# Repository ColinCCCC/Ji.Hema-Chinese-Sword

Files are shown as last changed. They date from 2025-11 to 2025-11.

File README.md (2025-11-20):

# 兵击中国剑『巽』



## 声明

本项目遵循[MIT协议](https://mitsloan.mit.edu/licensing)，允许自由使用、复制、修改、合并、发布、分发和商业化。

不保障项目绝对安全，使用本项目请自负一切后果。

本项目为减伤体育用品设计，请勿用于违反法律法规用途。

制作成品**无需用到任何工业设计专业知识**，如有兴趣，可跟随[下方教程](https://github.com/ColinCCCC/Ji.Hema-Chinese-Sword/tree/main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)进行制作。

## 成品数据

- 本项目由[风灵剑阁](https://space.bilibili.com/277525213?spm_id_from=333.337.0.0)进行指导，为用于兵击对练的中国剑钢剑设计，全长100cm，柄长22cm（计入剑首、剑格）。

- 剑身无渐薄，项目通过直接设计剑身形状，以符合真剑质量分布，并达成减伤要求。

- 倒角抛光前，剑条重量约530g。使用70%petg打印剑柄，并为所有孔位安装夹板螺母后，全重约700g。具体情况视材料与工艺而定。

- 经测试，若选用3mm65Mn或60Si2Mn板材，剑条刺弯压力约8.0kg。

## 使用教程

### 成品制作

#### 剑条切割

在淘宝等电商应用，搜索并查找提供**65Mn板材激光切割定制**服务的商家，按需选择合适的商品页面，并联系客服。

为商家提供所需的**DXF文件或DWG文件**，按需求说明**切割的数量与厚度**，待商家报价后，支付并提供收货地址，即可等待切割成品送达。

*所需DXF/DWG文件及其对应厚度如下：*

- 剑条【3mm】[blade.DXF](https://github.com/ColinCCCC/Ji.Hema-Chinese-Sword/blob/main/blade.DXF)
- 剑条【3mm】[blade.DWG](https://github.com/ColinCCCC/Ji.Hema-Chinese-Sword/blob/main/blade.DWG)

#### 手柄打印

若自备3D打印机，可以自行下载项目中的**STL文件**进行切片打印。

若无3D打印机，可在闲鱼搜索附近提供3D打印服务的商户，提供项目中的**STL文件**，打印后取货。

*所需STL文件及其对应厚度如下：*

- 剑柄（半边）[hdl.STL](https://github.com/ColinCCCC/Ji.Hema-Chinese-Sword/blob/main/hdl.STL)

#### 圆角与抛光

为保障对练安全性，**请务必对剑条进行圆角处理**。若希望追求美观性，可进一步对剑条表面进行抛光。

圆角与抛光需要用到砂带机或角磨机，可以选择自行打磨，或就近寻找五金店，请工作人员协助打磨。

#### 装配

剑柄采用4个M6*14，杆径8的夹板螺母固定，请自行购置。

### 设计修改

项目使用SOLIDWORKS2025进行设计，项目已附带所有原工程文件。

*所有SLDPRT文件如下：*

- 剑条 [blade.SLDPRT](https://github.com/ColinCCCC/Ji.Hema-Chinese-Sword/blob/main/blade.SLDPRT)

- 剑柄（半边）[hdl.SLDPRT](https://github.com/ColinCCCC/Ji.Hema-Chinese-Sword/blob/main/hdl.SLDPRT)

使用者可以在此基础上，按需求进行修改或再创作。

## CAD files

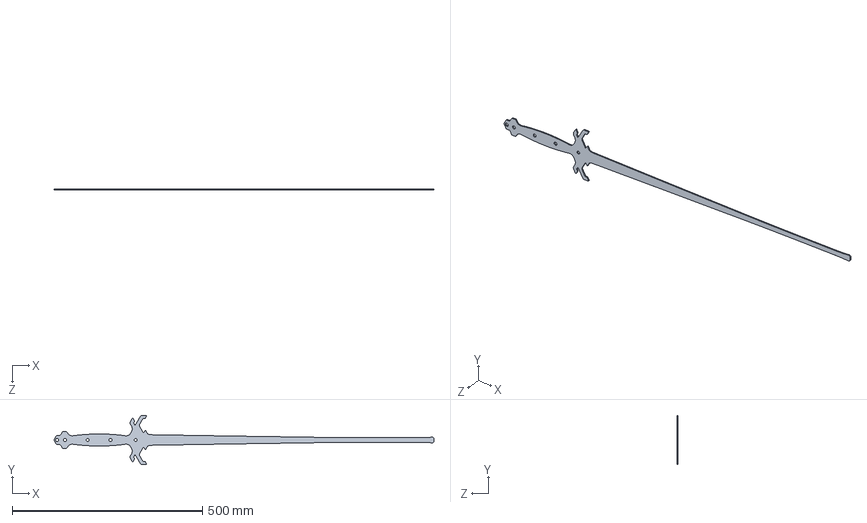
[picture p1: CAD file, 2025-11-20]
blade.SLDPRT
999.3 x 130.0 x 3.00 mm

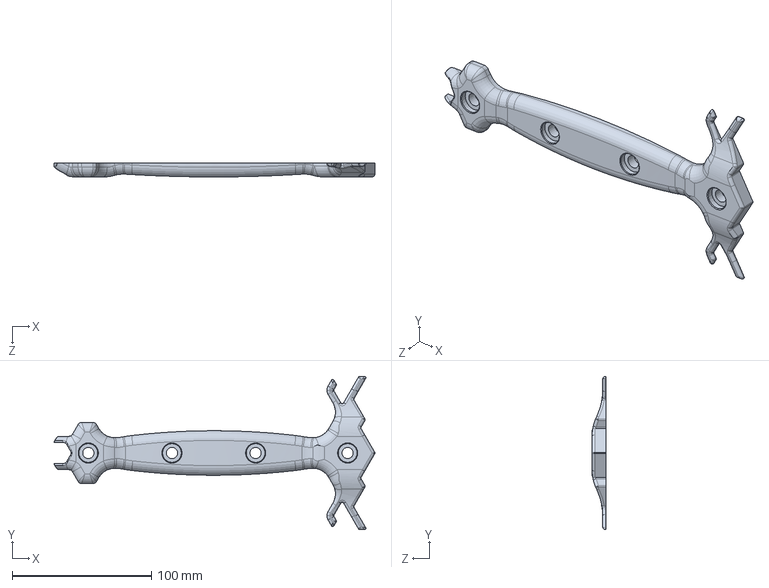
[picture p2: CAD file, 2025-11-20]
hdl.SLDPRT
230.2 x 110.0 x 10.0 mm

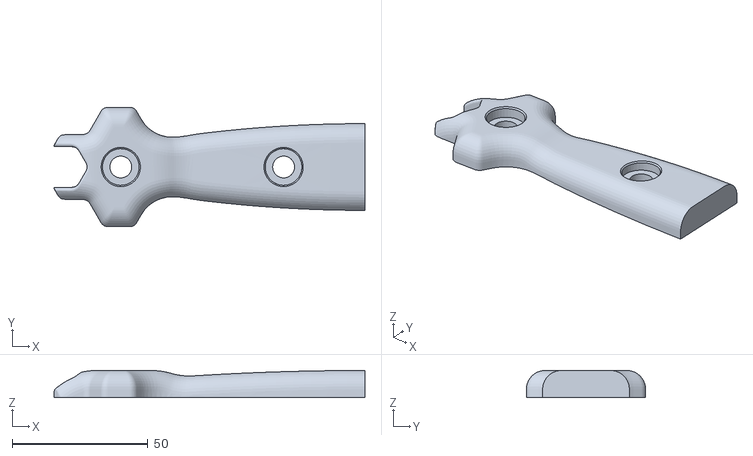
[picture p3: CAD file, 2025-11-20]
hdl_b.STL
114.6 x 44.0 x 10.00

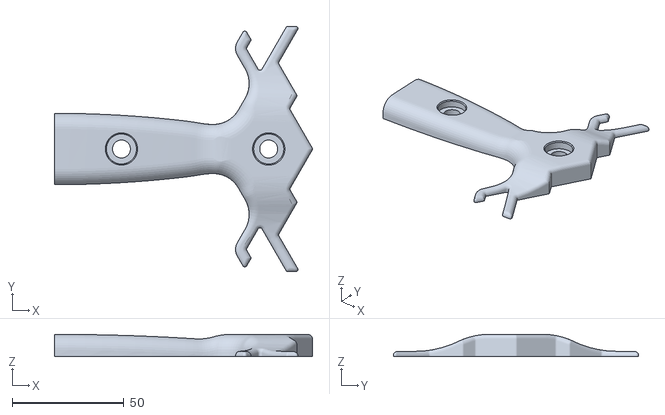
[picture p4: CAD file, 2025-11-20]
hdl_f.STL
115.6 x 110.0 x 10.00

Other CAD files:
blade.DXF
hdl.STL
